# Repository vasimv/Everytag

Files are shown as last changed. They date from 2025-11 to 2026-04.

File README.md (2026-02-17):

# Everytag
The firmware emulates Apple Airtag (up to 40 public keys rotating at default 10 minutes interval) and Google Find My Device (just one non-rotating key at the moment). It works on nRF52/54 chips and uses Zephyr. I've tried to optimize power consumption as much as could (microamperes range). MCU's watchdog is used to be sure it always works until battery dies.

One of biggest advantages of the firmware is ability to reconfigure all of its settings via BLE (python script is included), so you can change keys, transmitting power, broadcasting interval and such without reflashing. To minimize power consumption, the firmware accepts connections to change settings only for 2 seconds every minute and has simple password protection.

As beta test feature, it counts current time (if your board has 32.768kHz crystal) and saves current time to the flash periodically, so clock won't drift too much even if it gets reboot.

Also, it is possible to do OTA firmware update on nRF52/54 chips with at least 512KB flash/RRAM memory through mcumgr protocol. That includes nRF52832 (512KB version), nRF52833, nRF54L15. OTA won't work on nRF52805, nRF52810 but you can still change settings through BLE.

## Credits and useful links
Big thanks to OpenHaystack project for their great work: https://github.com/seemoo-lab/openhaystack

The firmware originated as a fork of macless-haystack project and has some of its code: https://github.com/dchristl/macless-haystack

To query locations you can use FindMy scripts: https://github.com/biemster/FindMy

To create Google FMDN key and query locations, use this: https://github.com/leonboe1/GoogleFindMyTools

## Hardware

The firmware has support (see boards/ subdirectory) and tested on these boards and beacons: NRF52DK (nRF52832), NRF54L15DK (nRF54L15), KKM C2 (nRF52805), KKM K4P (K5) with accelerometer (nRF52833), KKM P1 (nRF52810), KKM P11 (nRF52810), Fanstel NRF52805EVM (nRF52805), Minew HCB22E (nRF52832). For NRF52DK, KKM C2 and KKM K4P you will have to use button to turn it on after first flash. On other boards/beacons it'll start right after flashing. Only one LED will blink on the start (1 short, 2 long).

Button (first one on NRF52DK board) can be used to turn off/on. Long press the button until 1 short + 2 long LED flashes to start it on. Same long press for shutdown, it'll do two short flashes and issue sys_poweroff(), less than one microampere in that state. Power on/off status is stored into flash, so it'll stay same after battery replacement (will blink once after installing new battery and return to sleep if was turned off).

Additionally, i've included my design of beacon that has Qi/WPC wireless charging support (nRF52833, BQ51013B, BQ25121A), see hardware/ subdirectory. The goal was to make small and very thin beacon (50x20x2mm with LIR2016 li-ion battery). You can order these assembled on PCBWay https://www.pcbway.com/project/shareproject/Small_and_thin_50x20x2mm_Bluetooth_beacon_with_Qi_WPC_wireless_charging_f97170e6.html (around 35 USD per board).

## Compilation
Zephyr-based nRF Connect SDK 2.8.0 is required to compile the firmware.

myboards.h file has compilation-time settings (like how often switch to settings mode, etc). 

In the Visual Studio Code - click on nrfconnect plugin button, create build configuration for your board. Use following configuration files:

prj-smpsrv.conf - debug (through J-Link RTT interface) version with mcumgr support (for 512KB or bigger flash chips). You can use JlinkRTTViewer to connect and see debug messages on its console.

prj-smpsrv-lowpower.conf - no debug version for lowest power consumption and memory usage, with mcumgr support

prj.conf - debug version without mcumgr support (no mcuboot) for small memory chips - nRF52805, nRF52810, nRF52811

prj-lowpower.conf - no debug version for these chips

For nRF52DK/nrf52832 and nRF54L15DK - use nrf52832dk.overlay / nrf54l15dk.overlay files as "Extra Devicetree overlays"

## Running
It is recommended to erase all flash memory before first run to reset NVS storage where the firmware stores its settings.

Disconnect power source (remove battery) for 10-20 seconds and reconnect again after flashing through SWD or using RTT debug console, nrf chips often switch to high power consumption (up to few milliamps range) after using Jlink RTT interface and software reset doesn't help. So far, i haven't found way to avoid that.

By default, the firmware will start broadcasting dummy iBeacon packets with 7 seconds interval at very low power (-8dBm) with TX power field set as battery voltage (like 31 is 3.1 volts). This broadcast will stop as soon as you load Apple Airtag and/or Google FMDN key.

The beacon will use default MAC address (from MCU's registers programmed at factory) for iBeacon and settings broadcasts. You can figure out the address via debug console or using an BLE scanning app (nrfconnect from Nordic is quite good and free) on a smartphone.

## Changing settings via BLE
Every minute it will switch into settings mode for 2 seconds (configurable) and settings (including keys) can be changed by conn_beacon.py script (requires python 3) or by using android application that AI did generate for me (see below). Note, bluez isn't really perfect stack to work with BLE and the script may have troubles while connecting to the beacon. To fix that, you may try to disable/enable bluetooth or even reboot your computer.

The script is used for:
1. Changing its settings and/or writing current time to the beacon
2. Reading current time from the beacon
3. Switching the beacon into mcumgr OTA mode for one minute

All of these requires password authentication (default password is "abcdefgh", can be changed via settings mode too)

Note, after loading an Airtag key, MAC address in settings mode will be changed, it is recommended to set a specific MAC address for the settings mode when loading an Airtag key. Otherwise, you will have to figure out current MAC address via nrfconnect app or in a similar way.

Examples:
`python3 conn_beacon.py -i e7:93:3a:cc:f6:61 -c e7:93:3a:cc:f6:61 -a abcdefgh -n h45edc78 -f f1e101731f1e1b312272f812e521293a3f484414 -k ~/airtags/016WX1_keyfile -p 2 -g 1 -t 1 -w 1 -d 2`

This will connect to beacon with E7:93:3A:CC:F6:61 MAC address, change password to "h45edc78" load airtag key from 016WX1_keyfile, load FMDN key "f1e101731f1e1b312272f812e521293a3f484414", set maximum TX power (+4 or +8 dBm), allow broadcasting both Airtag and FMDN, switching every 2 seconds. You can omit some settings you don't want to change, only MAC address (-i) and authorization code (-a) is required.

`python3 conn_beacon.py -i e7:93:3a:cc:f6:61 -a h45edc78 -w 1`

This will connect to the beacon and synchronize its clock to current time.

`python3 conn_beacon.py -i e7:93:3a:cc:f6:61 -a h45edc78 -r 1`

This will connect to the beacon and read current time

To use OTA update feature, see flash_beacon.sh and flash_list.sh. Debug/lowpower versions of the mcumgr stuff may be uncompatible between each other, so you may get troubles with reflashing over bluetooth if flashed wrong version first. Settings are stored in separate region of flash/RRAM and they will be same after OTA, use full chip erase through SWD to get rid of old settings or use conn_beacon.py to program new ones.

## Using android application to change settings
Check subdirectory tagcheck for the android application. I have around zero knowledge about the android application development, so ChatGPT did wrote it for me. Sorry for its general ugliness, i'm not an UI guy. This is AndroidStudio project and you can compile it by yourself or use apk included.

"SCAN BLE" functionality will find all BLE stuff with RSSI is bigger than specififed value. This will help to find MAC address of your beacon (place it very close to the phone's bluetooth antenna, so RSSI will be bigger). You can tap on one of scanned results to fill target's MAC address to send settings instead of typing MAC manually.

On settings screen you can choose which settings to update on the Everytag beacon by activating their respective checkboxes. You have to set target MAC address and password (authorization code) to be able to reconfigure beacon. You will need to upload an airtag keyfile to the phone to change its broadcast key.

"Firmware Update" will upgrade firmware through BLE, you have to upload zephyr.signed.bin to your phone first.

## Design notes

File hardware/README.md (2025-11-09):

## Bluetooth beacon design with Qi/WPC charging

The goal of the project was to make thin and small BLE beacon that uses Li-Ion battery and can be recharged with wireless charging. Note, it may not work with all Qi/WPC chargers because small receiving charging coil, it is highly recommended to adapt charger by replacing its transmitting coil with small 20mm diameter coil. I've used Wurth 760308101104 coil with Adafruit 2162 Qi/WPC charger module.

Final size with LIR2016 battery - 50x20x2mm in thin variant. If height is not limited, then battery can be placed above the board and size will be 30x20mm. A ferrite gasket 20x15mm plate is strongly recommended to be glued on the receiving coil, i've used Wurth 74274119 in that role. 5x1mm round magnet can be placed in the hole on the board and transmitting antenna, so both coils will self-align while charge.

When placed on a Qi/WPC charger - reset pulse will be generated for the MCU, keep that in mind if you want to use with your own firmwares. BQ25121A is used in I2C-only configuration to simplify PCB design, you have to configure charging current, voltages and such during MCU initialization.

BQ25121A and 0402 sized components are quite hard to solder manually, so you may want to order them assembled! Link on PCBWay: https://www.pcbway.com/project/shareproject/Small_and_thin_50x20x2mm_Bluetooth_beacon_with_Qi_WPC_wireless_charging_f97170e6.html

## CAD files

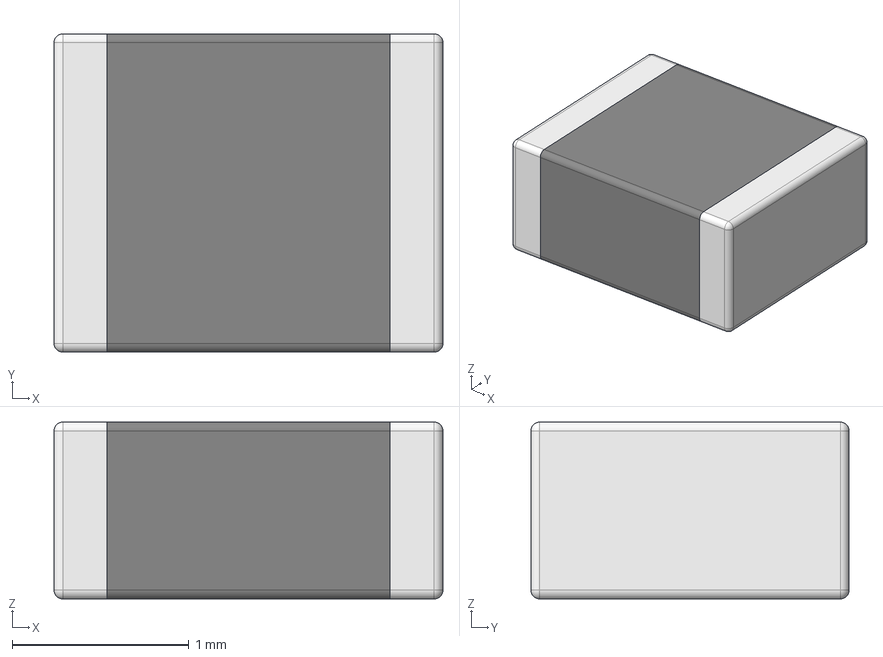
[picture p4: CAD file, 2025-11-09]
hardware/ALTIUM_EMBEDDED_MODELS/INDC2016X10N.step
2.20 x 1.80 x 1.00 mm

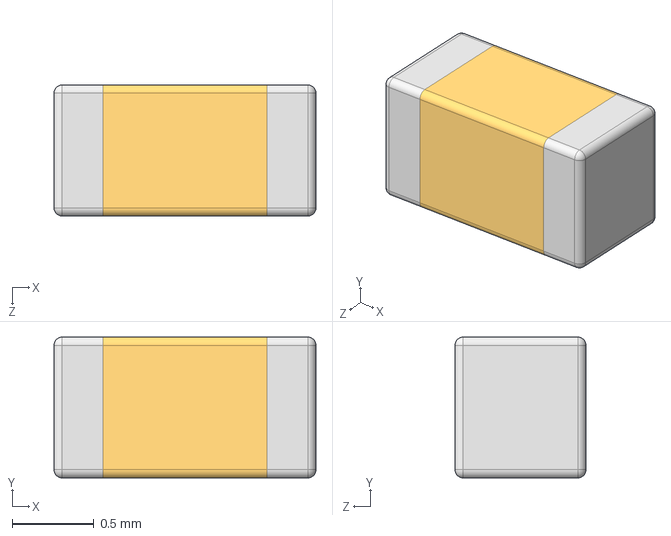
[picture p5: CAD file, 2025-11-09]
hardware/ALTIUM_EMBEDDED_MODELS/User Library-Chip Capacitor 0603.step
1.60 x 0.86 x 0.8 mm

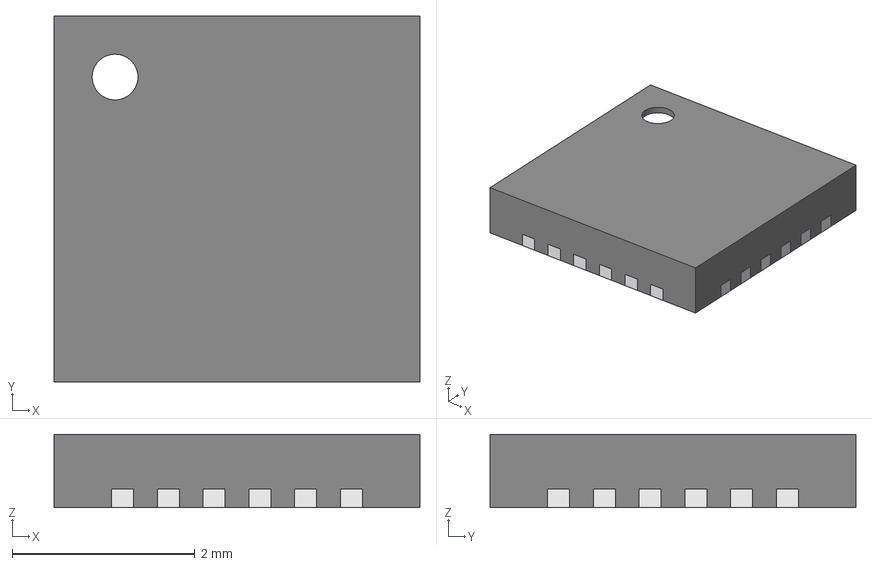
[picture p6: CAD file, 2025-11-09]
hardware/ALTIUM_EMBEDDED_MODELS/QFN50P400X400X80_HS-25N.step
4.00 x 4.00 x 0.801 mm
Thermal_Shape

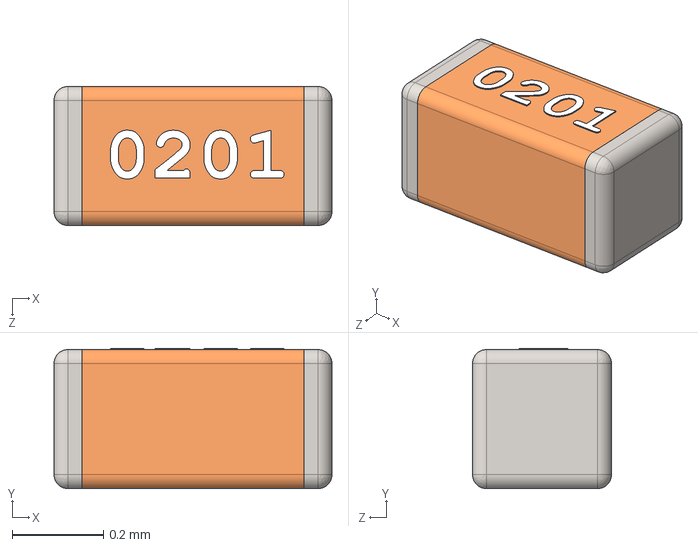
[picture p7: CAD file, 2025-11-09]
hardware/ALTIUM_EMBEDDED_MODELS/User Library-0201(0603M) Cap.step
0.61 x 0.307 x 0.305 mm

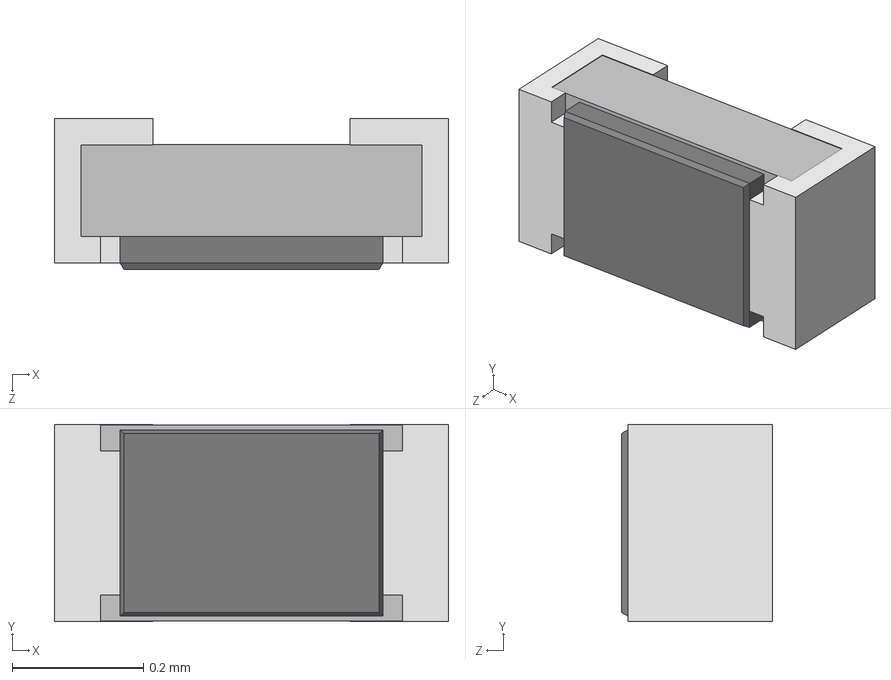
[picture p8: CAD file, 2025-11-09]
hardware/ALTIUM_EMBEDDED_MODELS/User Library-res0201-1.step
0.6 x 0.3 x 0.23 mm

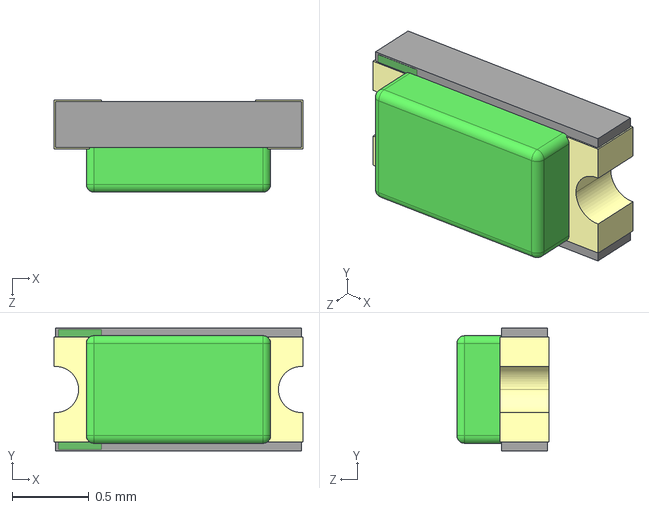
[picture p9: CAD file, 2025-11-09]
hardware/ALTIUM_EMBEDDED_MODELS/User Library-led_0603_green.step
1.62 x 0.8 x 0.6 mm

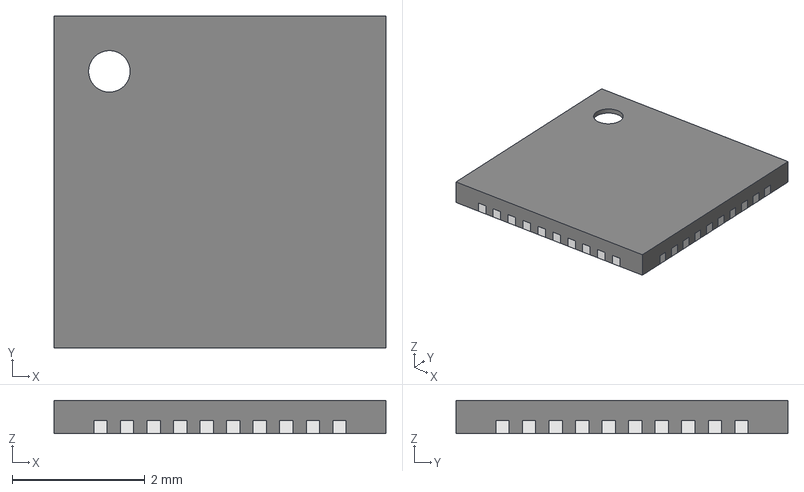
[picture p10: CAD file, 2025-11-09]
hardware/ALTIUM_EMBEDDED_MODELS/QFN40P500X500X50_HS-41N.step
5.00 x 5.00 x 0.501 mm
Thermal_Shape

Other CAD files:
hardware/ALTIUM_EMBEDDED_MODELS/User Library-led_0603_red.step

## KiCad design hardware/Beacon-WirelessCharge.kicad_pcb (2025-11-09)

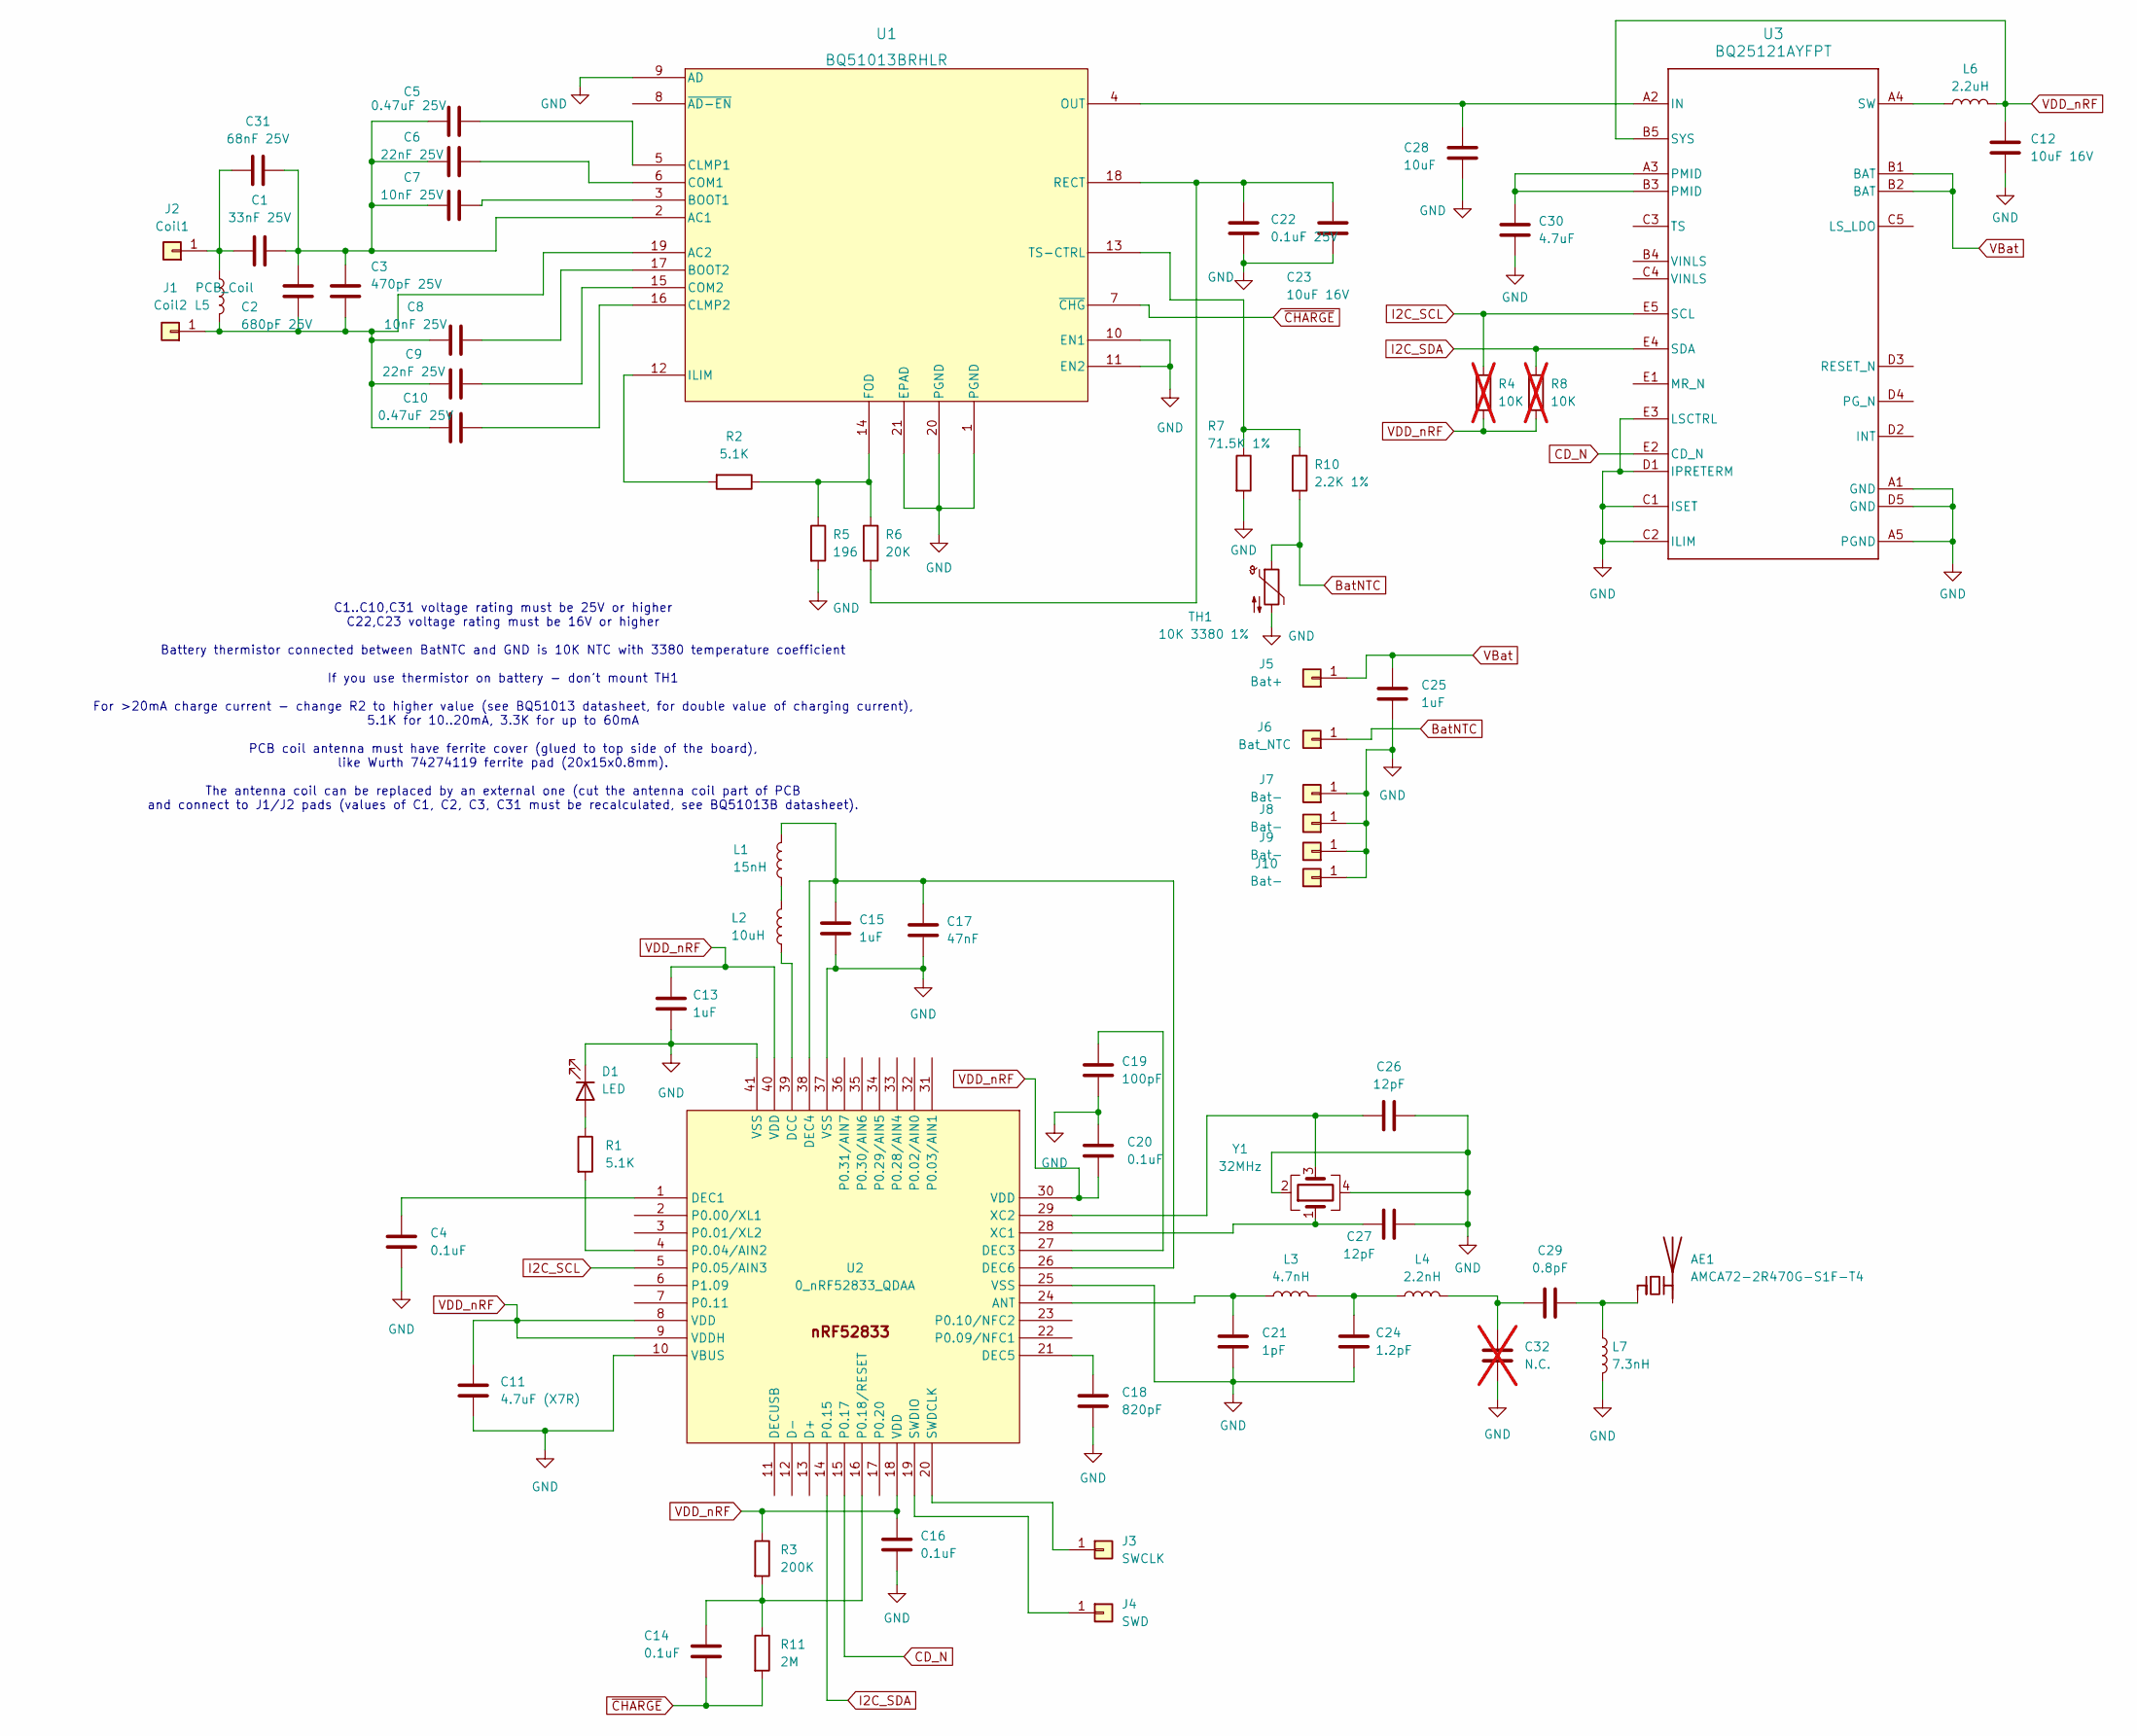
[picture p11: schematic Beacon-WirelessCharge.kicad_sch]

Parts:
AE1: AMCA72-2R470G-S1F-T4; Antenna_2450AT43A100
C1: 33nF 25V; C_0402_1005Metric
C2: 680pF 25V; C_0402_1005Metric
C3: 470pF 25V; C_0402_1005Metric
C4, C14, C16, C20: 0.1uF; C_0402_1005Metric
C5, C10: 0.47uF 25V; C_0402_1005Metric
C6, C9: 22nF 25V; C_0402_1005Metric
C7, C8: 10nF 25V; C_0402_1005Metric
C11: 4.7uF (X7R); C_0603_1608Metric
C12, C23: 10uF 16V; C_0603_1608Metric
C13, C15, C25: 1uF; C_0402_1005Metric
C17: 47nF; C_0402_1005Metric
C18: 820pF; C_0402_1005Metric
C19: 100pF; C_0402_1005Metric
C21: 1pF; C_0402_1005Metric
C22: 0.1uF 25V; C_0402_1005Metric
C24: 1.2pF; C_0402_1005Metric
C26, C27: 12pF; C_0402_1005Metric
C28: 10uF; C_0402_1005Metric
C29: 0.8pF; C_0402_1005Metric
C30: 4.7uF; C_0402_1005Metric
C31: 68nF 25V; C_0402_1005Metric
C32: N.C.; C_0402_1005Metric; not fitted
D1: LED; D_0402_1005Metric
J1: Coil2; Pin-1.5_1.5mm
J2: Coil1; Pin-1.5_1.5mm
J3: SWCLK; Pin-1.5_1.5mm
J4: SWD; Pin-1.5_1.5mm
J5: Bat+; Pin-1.5_1.5mm
J6: Bat_NTC; Pin-1.5_1.5mm
J7, J8, J9, J10: Bat-; Pin-1.5_1.5mm
L1: 15nH; L_0402_1005Metric
L2: 10uH; L_0603_1608Metric
L3: 4.7nH; L_0402_1005Metric
L4: 2.2nH; L_0402_1005Metric
L5: PCB_Coil; antenna 19x13mm
L6: 2.2uH; L_0603_1608Metric
L7: 7.3nH; L_0402_1005Metric
R1, R2: 5.1K; R_0402_1005Metric
R3: 200K; R_0402_1005Metric
R4, R8: 10K; R_0402_1005Metric; not fitted
R5: 196; R_0402_1005Metric
R6: 20K; R_0402_1005Metric
R7: 71.5K 1%; R_0402_1005Metric
R10: 2.2K 1%; R_0402_1005Metric
R11: 2M; R_0402_1005Metric
TH1: 10K 3380 1%; R_0402_1005Metric
U1: BQ51013BRHLR; RHL20_2P05X3P05
U2: 0_nRF52833_QDAA; _Applications_test_rsk_lib_RSK-ONLY_Nordic Active DB.DbLib_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; PART NUMBER nRF52833-QDAA
U3: BQ25121AYFPT; BGA25C40P5X5_247X253X50
Y1: 32MHz; Crystal_SMD_2016-4Pin_2.0x1.6mm

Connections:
BatNTC: J6.1, R10.2, TH1.1
CD_N: U2.15 (P0.17), U3.E2 (CD_N)
GND: C4.2, C11.2, C12.2, C13.2, C15.2, C16.2, C17.2, C18.2, C19.2, C20.1, C21.2, C22.2, C23.2, C24.2, C25.2, C26.2, C27.2, C28.2, C30.2, C32.2, D1.1 (K), J7.1, J8.1, J9.1, J10.1, L7.2, R5.2, R7.2, TH1.2, U1.1 (PGND), U1.9 (AD), U1.10 (EN1), U1.11 (EN2), U1.20 (PGND), U1.21 (EPAD), U2.10 (VBUS), U2.25 (VSS), U2.37 (VSS), U2.41 (VSS), U3.A1 (GND), U3.A5 (PGND), U3.C1 (ISET), U3.C2 (ILIM), U3.D1 (IPRETERM), U3.D5 (GND), U3.E3 (LSCTRL), Y1.2, Y1.4
I2C_SCL: R4.1, U2.5 (P0.05/AIN3), U3.E5 (SCL)
I2C_SDA: R8.1, U2.14 (P0.15), U3.E4 (SDA)
unnamed: AE1.1 (FEED), C29.2, L7.1
unnamed: C24.1, L3.2, L4.1
unnamed: C29.1, C32.1, L4.2
unnamed: C30.1, U3.A3 (PMID), U3.B3 (PMID)
unnamed: D1.2 (A), R1.1
unnamed: C2.2, C3.2, C8.1, C9.1, C10.1, J1.1, L5.2, U1.19 (AC2)
unnamed: C1.1, C31.1, J2.1, L5.1
unnamed: J3.1, U2.20 (SWDCLK)
unnamed: J4.1, U2.19 (SWDIO)
unnamed: L1.1, L2.2
unnamed: C1.2, C2.1, C3.1, C5.1, C6.1, C7.1, C31.2, U1.2 (AC1)
unnamed: C7.2, U1.3 (BOOT1)
unnamed: C8.2, U1.17 (BOOT2)
unnamed: C5.2, U1.5 (CLMP1)
unnamed: C10.2, U1.16 (CLMP2)
unnamed: C6.2, U1.6 (COM1)
unnamed: C9.2, U1.15 (COM2)
unnamed: R2.1, R5.1, R6.1, U1.14 (FOD)
unnamed: R2.2, U1.12 (ILIM)
unnamed: C28.1, U1.4 (OUT), U3.A2 (IN)
unnamed: C22.1, C23.1, R6.2, U1.18 (RECT)
unnamed: R7.1, R10.1, U1.13 (TS-CTRL)
unnamed: C21.1, L3.1, U2.24 (ANT)
unnamed: L2.1, U2.39 (DCC)
unnamed: C4.1, U2.1 (DEC1)
unnamed: C19.1, U2.27 (DEC3)
unnamed: C15.1, C17.1, L1.2, U2.26 (DEC6), U2.38 (DEC4)
unnamed: C18.1, U2.21 (DEC5)
unnamed: R1.2, U2.4 (P0.04/AIN2)
unnamed: C14.1, R3.2, R11.1, U2.16 (P0.18/RESET)
unnamed: C27.1, U2.28 (XC1), Y1.1
unnamed: C26.1, U2.29 (XC2), Y1.3
unnamed: L6.1, U3.A4 (SW)
VBat: C25.1, J5.1, U3.B1 (BAT), U3.B2 (BAT)
VDD_nRF: C11.1, C12.1, C13.1, C16.1, C20.2, L6.2, R3.1, R4.2, R8.2, U2.8 (VDD), U2.9 (VDDH), U2.18 (VDD), U2.30 (VDD), U2.40 (VDD), U3.B5 (SYS)
~CHARGE: C14.2, R11.2, U1.7 (~CHG)

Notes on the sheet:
C1..C10,C31 voltage rating must be 25V or higher C22,C23 voltage rating must be 16V or higher Battery thermistor connected between BatNTC and GND is 10K NTC with 3380 temperature coefficient If you use thermistor on battery - don't mount TH1 For >20mA charge current - change R2 to higher value (see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

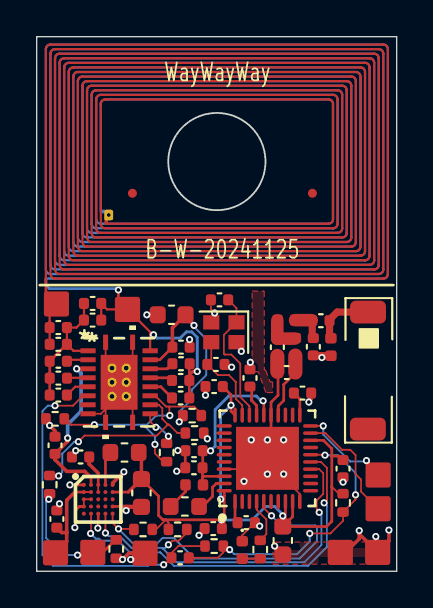
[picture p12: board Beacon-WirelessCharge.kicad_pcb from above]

Board: 2 copper layers, 20.0 x 29.7 mm, 68 parts (1 on the bottom side), 41 nets.

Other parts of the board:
Fiducial_0.5_1_A, Fiducial_0.5_1_B: Fiducial_0.5mm_Mask1mm

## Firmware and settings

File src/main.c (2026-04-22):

/*
 * Copyright (c) 2018 Henrik Brix Andersen <henrik@brixandersen.dk>
 *
 * SPDX-License-Identifier: Apache-2.0
 */

#include <stdlib.h>
#include <zephyr/types.h>
#include <stddef.h>
#include <zephyr/sys/printk.h>
#include <zephyr/sys/util.h>
#include <zephyr/sys/byteorder.h>

#include <zephyr/bluetooth/bluetooth.h>
#include <zephyr/bluetooth/hci.h>
#include <zephyr/bluetooth/hci_vs.h>
#include <zephyr/sys/poweroff.h>

#include <zephyr/kernel.h>
#include <zephyr/device.h>
#include <zephyr/drivers/gpio.h>
#include <zephyr/bluetooth/controller.h>
#include <zephyr/pm/pm.h>
#include <zephyr/pm/device.h>
#include <zephyr/drivers/adc.h>
#include <zephyr/drivers/i2c.h>
#include <zephyr/drivers/timer/system_timer.h>
#include <zephyr/sys/reboot.h>
#include <zephyr/irq.h>
#include <zephyr/drivers/hwinfo.h>

#include "myboards.h"
#include "settings.h"
#include "watchdog.h"
#ifdef USE_BQ25121A
#include "bq2512x.h"
#endif
#ifdef USE_LIS2DW12
#include "lis2dw12.h"
#endif

#define BROADCAST_INTERVAL_MIN 1500 // 938ms
#define BROADCAST_INTERVAL_MAX 1590 // 994ms

#if !DT_NODE_EXISTS(DT_PATH(zephyr_user)) || \
	!DT_NODE_HAS_PROP(DT_PATH(zephyr_user), io_channels)
#warning "No suitable devicetree node, battery check disabled"
#define NO_BATTERY_CHECK
#endif

#ifndef NO_BATTERY_CHECK
#define DT_SPEC_AND_COMMA(node_id, prop, idx) \
	ADC_DT_SPEC_GET_BY_IDX(node_id, idx),

/* Data of ADC io-channels specified in devicetree. */
static const struct adc_dt_spec adc_channels[] = {
	DT_FOREACH_PROP_ELEM(DT_PATH(zephyr_user), io_channels,
			     DT_SPEC_AND_COMMA)
};
#endif

#if CONFIG_GPIO
#define LED_NODE DT_NODELABEL(led0)
static const struct gpio_dt_spec led_spec = GPIO_DT_SPEC_GET(LED_NODE, gpios);
#define GPIO_ID DT_NODELABEL(gpio0)
#ifdef HAS_LED1_SWITCH
#define LED1_NODE DT_NODELABEL(led1)
static const struct gpio_dt_spec gate_spec = GPIO_DT_SPEC_GET(LED1_NODE, gpios);
#endif
#endif

#ifdef HAS_I2C_KXTJ3
#define I2C0_NODE DT_NODELABEL(kxtj3)
static const struct i2c_dt_spec dev_i2c = I2C_DT_SPEC_GET(I2C0_NODE);
const struct device *const i2c_dev = DEVICE_DT_GET(DT_NODELABEL(i2c0));
#endif

#ifdef USE_BUTTON
static const struct gpio_dt_spec sw0 = GPIO_DT_SPEC_GET(DT_ALIAS(sw0), gpios);
#endif

void blink_led(int num, int fast) {
	int err;

#if CONFIG_GPIO
#if CONFIG_PM_DEVICE_RUNTIME
  	err = pm_device_action_run(DEVICE_DT_GET(DT_NODELABEL(gpio0)), PM_DEVICE_ACTION_RESUME);
	if (err)
		printk("Warning: Can't turn on gpio0 (err %d)\n", err);
#endif
	gpio_pin_configure_dt(&led_spec, GPIO_OUTPUT_INACTIVE);
	k_sleep(fast ? K_MSEC(250) : K_MSEC(1000));
	for (int i = 0; i < (2*num); i++) {
		gpio_pin_toggle_dt(&led_spec);
		k_sleep(fast ? K_MSEC(100) : K_MSEC(200));
	}
#if CONFIG_PM_DEVICE_RUNTIME
	gpio_pin_configure_dt(&led_spec, GPIO_DISCONNECTED);
	err = pm_device_action_run(DEVICE_DT_GET(DT_NODELABEL(gpio0)), PM_DEVICE_ACTION_SUSPEND);
	if (err)
		printk("Warning: Can't turn off gpio0 (err %d)\n", err);
#endif
#endif
}

int lastBatteryVoltage = 0;

#ifdef USE_BQ25121A
int check_charging() {
	return bq2512x_is_charging();
}

int battery_voltage(void) {
	return bq2512x_lastVoltage;
}
#else
int check_charging() {
	// There is no way to check if we're charging on boards without BQ25121A
	return 0;
}

int battery_voltage(void) {
#ifndef NO_BATTERY_CHECK
	int err;
	int32_t val_mv;
	int16_t buf = 0;
	uint8_t level = 0;
	int64_t sum_mv = 0;
	int i;

#if CONFIG_PM_DEVICE_RUNTIME
	err = pm_device_action_run(DEVICE_DT_GET(DT_NODELABEL(adc)), PM_DEVICE_ACTION_RESUME);
	if (err)
		printk("Warning: Can't turn on adc0 (err %d)\n", err);
#endif
	struct adc_sequence sequence = {
		.buffer = &buf,
		/* buffer size in bytes, not number of samples */
		.buffer_size = sizeof(buf),
	};

	if (!device_is_ready(adc_channels[0].dev)) {
		printk("ADC controller device not ready\n");
		return level;
	}
	err = adc_channel_setup_dt(&adc_channels[0]);
	if (err < 0) {
		printk("Could not setup channel #%d (%d)\n", 0, err);
		return level;
	}
	(void)adc_sequence_init_dt(&adc_channels[0], &sequence);

	// read adc 8 times to average
	for (i = 0; i < BATTERY_ADC_SAMPLES; i++) {
		err = adc_read(adc_channels[0].dev, &sequence);
		if (err < 0) {
			printk("Could not read (%d)\n", err);
		return level; 
		}

		val_mv = buf;
		err = adc_raw_to_millivolts_dt(&adc_channels[0], &val_mv);
		if (err < 0) {
			printk(" (value in mV not available)\n");
			return level; 
		}
		k_sleep(K_MSEC(5));
		sum_mv += val_mv;
	}
	val_mv = BATTERY_MULTIPLIER * (sum_mv / BATTERY_ADC_SAMPLES);

	printk("voltage level: %d\n", val_mv);
#if CONFIG_PM_DEVICE_RUNTIME
	err = pm_device_action_run(DEVICE_DT_GET(DT_NODELABEL(adc)), PM_DEVICE_ACTION_SUSPEND);
	if (err)
		printk("Warning: Can't turn off adc0 (err %d)\n", err);
#endif

  lastBatteryVoltage = val_mv;
	return val_mv;
#else
	return 0;
#endif
}
#endif


// airtag advertising data
struct bt_data adv_airtag[] = {
  BT_DATA_BYTES(BT_DATA_MANUFACTURER_DATA,
          0x4c, 0x00, 0x02, 0x15, 0x18, 0xee, 0x15, 0x16,
          0x01, 0x6b, 0x4b, 0xec, 0xad, 0x96, 
          0xbc, 0xb9, 0x6d, 0x16, 0x6e, 0x97, 
          0x00, 0x00, 0x00, 0x00, 0x00, 0x00, 0x00, 0x00, 0x00
  ),
};

// fmdn advertising data
struct bt_data adv_fmdn[] = {
  BT_DATA_BYTES(BT_DATA_FLAGS, BT_LE_AD_NO_BREDR | BT_LE_AD_GENERAL),
  BT_DATA_BYTES(
    0x16, 0xAA, 0xFE, 0x41,
    // public key
    0x00, 0x00, 0x00, 0x00, 0x00, 0x00, 0x00, 0x00, 0x00, 0x00, 0x00, 0x00, 0x00, 0x00, 0x00, 0x00, 0x00, 0x00, 0x00, 0x00,
    // status
    0xc0
  ),
};

struct bt_data adv_ibeacon[] = {
  BT_DATA_BYTES(BT_DATA_FLAGS, BT_LE_AD_NO_BREDR),
  BT_DATA_BYTES(    0xff,       /* Manufacturer Specific Data (type 0xff) */
              0x4c, 0x00, /* Apple */
              0x02, 0x15, /* iBeacon */
              0x18, 0xee, 0x15, 0x16, /* UUID[15..12] */
              0x01, 0x6b, /* UUID[11..10] */
              0x4b, 0xec, /* UUID[9..8] */
              0xad, 0x96, /* UUID[7..6] */
              0xbc, 0xb9, 0x6d, 0x16, 0x6e, 0x97, /* UUID[5..0] */
              0x1, 0x1, /* Major */
              0x1, 0x1, /* Minor */ /* Hint (0x00) */
        0x0,
)
};

// MAC address (calculated from airtag key unless only FMDN broadcasting)
uint8_t bleAddr[6] = {0xFF, 0xBB, 0xCC, 0xDD, 0xEE, 0xFF};

static uint8_t offline_finding_adv_template[] = {
	0x1e,		/* Length (30) */
	0xff,		/* Manufacturer Specific Data (type 0xff) */
	0x4c, 0x00, /* Company ID (Apple) */
	0x12, 0x19, /* Offline Finding type and length */
	0xAA,		/* Status */
	0x00, 0x00, 0x00, 0x00, 0x00, 0x00, 0x00, 0x00,
	0x00, 0x00, 0x00, 0x00, 0x00, 0x00, 0x00, 0x00,
	0x00, 0x00, 0x00, 0x00, 0x00, 0x00,
	0x00, /* First two bits */
	0x00, /* Hint (0x00) */
};

uint8_t airtag_data_store[sizeof(offline_finding_adv_template)];
uint8_t fmdn_data_store[25];

#ifdef USE_ACCELEROMETER

// Make 7-bits array from accelerometer movements data
int calc_accel_byte() {
  int res = 0;
  
  // bit 0 - movements in 0..10 minutes
  // bit 1 - in 10..30 minutes
  // bit 2 - in 30..60 minutes
  // bit 3 - in 1..3 hours
  // bit 4 - in 3..6 hours
  // bit 5 - in 6..12 hours
  // bit 6 - in 12..24 hours
  if (accel_movement(0, 10))
    res |= 0x01;
  if (accel_movement(10, 30))
    res |= 0x02;
  if (accel_movement(30, 60))
    res |= 0x04;
  if (accel_movement(60, 180))
    res |= 0x08;
  if (accel_movement(180, 360))
    res |= 0x10;
  if (accel_movement(360, 720))
    res |= 0x20;
  if (accel_movement(720, 1440))
    res |= 0x40;
    
  return res;
}
#endif

// Status byte behaviour
// first two bytes - specific byte to broadcast as status for Airtag and FMDN
// 0x10000 - broadcast first byte as status in airtag
// 0x100000 - broadcast second byte as status in FMDN
// 0x20000 - broadcast incrementing (every changeInterval) byte as status in airtag
// 0x200000 - broadcast incrementing byte as status in FMDN
// 0x30000 - broadcast battery voltage as status in airtag (32 - 3.2V)
// 0x300000 - broadcast battery voltage as status in FMDN
// 0x40000 - broadcast battery level (0..3) in airtag with first byte, binary OR
// 0x400000 - broadcast battery level (1..3) in FMDN with second byte, binary OR
// 0x50000 - every minute switch between broadcasting battery voltage, accelerometer and temperature in airtag
// 0x500000 - every minute switch between broadcasting battery voltage, accelerometer and temperature in airtag

// What we're currently sending in status byte (with 0x50000 and 0x500000)
// 0 - battery voltage, 1 - accelerometer, 2 - temperature
static int what_in_status = 2;

static int keys_changes = 0;

// Update status byte in Airtag/FMDN advertisement broadcasts (see settings.h)
void update_status_byte() {
  uint8_t statusAirtag, statusFmdn;
  int bAirtag, bFmdn;

  what_in_status++;
  if (what_in_status > 2)
    what_in_status = 0;

  statusAirtag = statusFlags & 0xff;
  statusFmdn = (statusFlags & 0xff00) >> 8;
  bAirtag = (statusFlags & 0xf0000) >> 16;
  bFmdn = (statusFlags & 0xf00000) >> 20;
  printk("update_status_byte: battery: %d Airtag %d:%02X, %d:%02X\n", lastBatteryVoltage, bAirtag, statusAirtag, bFmdn, statusFmdn);
  // Setting status for airtag
  switch (bAirtag) {
    case 1:
      // Broadcast first byte from statusFlags as is
      break;
    case 2:
      // Broadcast incrementing byte as status byte
      statusAirtag = keys_changes & 0xff;
      break;
    case 3:
    case 5:
      // Broadcast battery voltage in status byte
      statusAirtag = lastBatteryVoltage / 100;
      if ((bAirtag == 3) || (what_in_status == 0))
        break;
      #ifdef USE_ACCELEROMETER
      if (what_in_status == 1) {
        statusAirtag = 0x80 | calc_accel_byte();
        printk("update_status_byte: switching to acceldata %02x\n", (int) statusAirtag);
      }
      if (what_in_status == 2) {
        // Send temperature in -10..53C range as positive 6-bit integer (-10 is 0, 53 is 63)
        int tmpTemp = (accelTemperature + 5) / 10 + 10;
        if (tmpTemp < 0)
          tmpTemp = 0;
        if (tmpTemp > 63)
          tmpTemp = 63;
        statusAirtag = 0x40 | tmpTemp;
        printk("update_status_byte: switching to temperature %02x\n", (int) statusAirtag);
      }
      #endif
      break;
    case 4:
      // Broadcast battery status
      int battery = 3;
      if (lastBatteryVoltage > BATTERY_LEVEL_FULL)
        battery = 0;
      else {
        if (lastBatteryVoltage > BATTERY_LEVEL_NORMAL)
          battery = 1;
        else {
          if (lastBatteryVoltage > BATTERY_LEVEL_LOW)
            battery = 2;
          else
            battery = 3;
        }
      }
      statusAirtag |= (battery << 6);
      break;
    default:
      break;
  }
  airtag_data_store[6] = statusAirtag;

  // Setting status for FMDN
  switch (bFmdn) {
    case 1:
      // Broadcast first byte from statusFlags as is
      break;
    case 2:
      // Broadcast incrementing byte as status byte
      statusFmdn = keys_changes & 0xff;
      break;
    case 3:
    case 5:
      // Broadcast battery voltage in status byte
      statusFmdn = lastBatteryVoltage / 100;
      #ifdef USE_ACCELEROMETER
      if (what_in_status == 1)
        statusFmdn = 0x80 | calc_accel_byte();
      if (what_in_status == 2) {
        // Send temperature in -10..53C range as positive 6-bit integer (-10 is 0, 53 is 63)
        int tmpTemp = (accelTemperature + 5) / 10 + 10;
        if (tmpTemp < 0)
          tmpTemp = 0;
        if (tmpTemp > 63)
          tmpTemp = 63;
        statusFmdn = 0x40 | tmpTemp;
      }
      #endif
      break;
    case 4:
      // Broadcast battery status
      int battery = 0;
      if (lastBatteryVoltage > BATTERY_LEVEL_NORMAL)
        battery = 1;
      else {
        if (lastBatteryVoltage > BATTERY_LEVEL_LOW)
          battery = 2;
        else {
          if (lastBatteryVoltage > 0)
            battery = 3;
          else
            battery = 0;
        }
      }
      statusFmdn |= (battery << 5);
      break;
    default:
      break;
  }
  fmdn_data_store[23] = statusFmdn;
}

/*
 * set_addr_from_key will set the bluetooth address from the first 6 bytes of the key used to be advertised
 */
void set_addr_from_key(const char *key)
{
	/* copy first 6 bytes */
	bleAddr[5] = key[0] | 0b11000000;
	bleAddr[4] = key[1];
	bleAddr[3] = key[2];
	bleAddr[2] = key[3];
	bleAddr[1] = key[4];
	bleAddr[0] = key[5];
}

/*
 * fill_adv_template_from_key will set the advertising data based on the remaining bytes from the advertised key
 */
void fill_adv_template_from_key(const char *key)
{
	memcpy(&offline_finding_adv_template[7], &key[6], 22);
	/* append two bits of public key */
	offline_finding_adv_template[29] = key[0] >> 6;
}

/*
 * setAdvertisementKey will setup the key to be advertised
 *
 * @param[in] key public key to be advertised
 * @param[out] bleAddr bluetooth address to setup
 * @param[out] data raw data to advertise
 *
 * @returns raw data size
 */
uint8_t setAdvertisementKey(const char *key, uint8_t **data)
{
  uint8_t status_save;

	set_addr_from_key(key);
	fill_adv_template_from_key(key);

	*data = airtag_data_store;
  status_save = airtag_data_store[6];
	memcpy(*data, offline_finding_adv_template, sizeof(offline_finding_adv_template));
  airtag_data_store[6] = status_save;
	return sizeof(offline_finding_adv_template);
}
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
int main(void)
{
	int err;
	int badPower = 0;
  int button_at_start = 0;
	
	my_wdt_init();

	printk("Beacon starting\n");

	blink_led(1, 1);
#ifdef USE_BUTTON
  /* Configure button pin */
	err = gpio_pin_configure_dt(&sw0, GPIO_INPUT);
	if (err < 0) {
		printk("Could not configure sw0 GPIO (%d)\n", err);
		return 0;
	}
  if (gpio_pin_get(sw0.port, sw0.pin) > 0)
    button_at_start = 1;
#endif

#ifdef HAS_LED1_SWITCH
	// Turn off mosfet
	gpio_pin_configure_dt(&gate_spec, GPIO_OUTPUT_ACTIVE);
#endif

	my_wdt_feed();
	init_settings();

#ifdef USE_BUTTON
  // Check if wake up button is pressed or go to power down state
  if (button_at_start) {
    printk("Button is pressed, turning on!\n");
    turnedOn = 1;
    update_turnedOn();
  } else {
    // If we weren't turned on by button then go to sleep again
    if (!turnedOn) {
      printk("We are not turned on, sleep again!\n");
      k_sleep(K_MSEC(500));
      my_poweroff();
      return 0;
    }
  }
#endif

#ifdef USE_BQ25121A
	// Repeat twice at start to be sure the bq25121a received settings
	bq2512x_reinit(1, SYS_VOLTAGE, CHARGE_CURRENT, PRECHARGE_CURRENT);
	k_sleep(K_MSEC(10));
	bq2512x_reinit(1, SYS_VOLTAGE, CHARGE_CURRENT, PRECHARGE_CURRENT);
#endif
#ifdef USE_ACCELEROMETER
  for (int i = 0; i < 3; i++)
    if (!accel_init())
      break;
  // Turn off accelerometer if threshold is zero
  if (accelThreshold <= 0)
    (void) accel_powerdown();
#endif

  // Set FMDN advertising data
  switch_fmdn_key(0);

	printk("keys in memory = %d\n", numKeys);
  currentKey = 0;
	switch_airtag_key(currentKey);
  if (flagAirtag || flagFmdn)
    set_MAC_addr(bleAddr);
  else
    if (settingsMAC[0] != 0 && settingsMAC[5] != 0)
      set_MAC_addr(settingsMAC);

  broadcastingAnything = 0;
  broadcastingAirtag = 0;
  broadcastingFmdn = 0;
  broadcastingSettings = 0;

	update_battery();
  update_status_byte();

	/* Initialize the Bluetooth Subsystem */
	err = bt_enable(NULL);
	printk("Bluetooth initialized (err=%d)\n", err);
	
	set_power(txPower);
	my_wdt_feed();
	blink_led(2, 0);

  // Broadcast ibeacon every 7..8 seconds if no airtag or fmdn
  if (!flagAirtag && !flagFmdn)
    broadcast_ibeacon();

  #ifdef USE_BUTTON
  // Wait for button release before getting into main loop
  while (gpio_pin_get(sw0.port, sw0.pin) > 0) {
    k_sleep(K_MSEC(1000));
    my_wdt_feed();
  }
  #endif

	while (1) {
    // In settings mode we do only 2 seconds delay
    if (broadcastingSettings)
      k_sleep(K_MSEC(1000));
    else
      k_sleep(K_MSEC(1000 * multPeriod));
		my_wdt_feed();

		if (chargeLockCounter > 0) 
			chargeLockCounter = chargeLockCounter - multPeriod;

    // Check if we're in settings mode
    if (broadcastingSettings) {
      // Check if settings mode ended
      if (k_uptime_seconds() >= tEndSettings) {
        // Check if someone did connect, wait 2 seconds for auth
        if (connectedGatt || authorizedGatt) {
          k_sleep(K_MSEC(2000));
          my_wdt_feed();
        }
        if (authorizedGatt) {
          k_sleep(K_MSEC(4000));
          my_wdt_feed();
        }
        // Check if we have to wait for firmware upload
        if (pauseUpload) {
          printk("Pause for 60 seconds for firmware upload\n");
          for (int i = 0; i < 15; i++) {
            k_sleep(K_MSEC(4000));
            store_time();
            my_wdt_feed();
          }
          reset_MCU();
          break;
        }

        stop_settings_adv();
        broadcastingSettings = 0;
        broadcastingAnything = 0;
        broadcastingFmdn = 0;
        broadcastingAirtag = 0;
        // Set MAC address back
        bt_disable();
        if (flagAirtag || flagFmdn)
          set_MAC_addr(bleAddr);
        bt_enable(NULL);
        set_power(txPower);
        // Do we have to reset?
        if (needsReset) {
          reset_MCU();
          break;
        }
        // Broadcast ibeacon every 7..8 seconds if no airtag or fmdn
        if (!flagAirtag && !flagFmdn)
          broadcast_ibeacon();
      }

    } else {
      // Update time in NVS storage
      if (k_uptime_seconds() >= (tLastTimeSave + INTERVAL_TIMESAVE)) { 
        tLastTimeSave = k_uptime_seconds();
        store_time();
      }
      // Update battery and store time every minute
      if (k_uptime_seconds() >= (tLastBatteryCheck + INTERVAL_BATTERYCHECK)) {
        tLastBatteryCheck = k_uptime_seconds();
        update_battery();      
        // Update status byte in airtag and fmdn
        update_status_byte();
        if (flagAirtag)
          switch_airtag_key(currentKey);
        if (flagAirtag || flagFmdn)
          broadcast();

				#ifdef BATTERY_UVLO_SHUTDOWN
				// On Li-Ion battery we have to monitor battery voltage and switch to power-save mode when it is too low
				if (battery_voltage() < BATTERY_LOW_VOLTAGE) {
					// Skip UVLO shutdown for one hour if charging is detected
					if (check_charging())
						chargeLockCounter = 3600;

          // Shutdown if we are not charging and battery voltage is too low for 5 minutes at least
					if (chargeLockCounter <= 0) {
						badPower++;
						if (badPower > 5) {
							printk("Battery voltage is too low! Shutting down!\n");
							bt_le_adv_stop();
							#ifdef USE_BQ25121A
							// Fully turn off the system through shipping mode
							bq2512x_shipmode();
							#endif
							my_poweroff();
              return 0;
							// Never should reach here but who knows... Turning off broadcasts, do nothing.
							while (battery_voltage() < BATTERY_LOW_VOLTAGE) {
								update_battery();
								k_sleep(K_MSEC(4000));
								my_wdt_feed();
							}
              reset_MCU();
              break;
						}
					} else {
						printk("Charging in progress was detected, skipping UVLO shutdown\n");
						badPower = 0;
					}
				} else
					badPower = 0;
				#endif
      }

      // Will shutdown after few minutes if no keys loaded and not in charging mode
      #ifdef SHUTDOWN_NOKEYS
      if (!flagAirtag && !flagFmdn && !check_charging() && (k_uptime_seconds() > SHUTDOWN_NOKEYS)) {
        printk("No keys loaded, shutting down!\n");
        blink_led(2, 1);
        #ifdef USE_BQ25121A
        bq2512x_shipmode();
        #endif
        my_poweroff();
        // Never should reach this but who knows...
        k_sleep(K_MSEC(4000));
        reset_MCU();
      }
      #endif

      
      // Switch to settings mode every minute for few seconds
      if (k_uptime_seconds() >= (tLastSettingsMode + INTERVAL_SETTINGS)) {
        tLastSettingsMode = k_uptime_seconds();
        tEndSettings = k_uptime_seconds() + SETTINGS_WAIT;
        bt_le_adv_stop();
        bt_disable();
        // We use other MAC and low power in settings mode
        if (settingsMAC[0] != 0 && settingsMAC[5] != 0)
          set_MAC_addr(settingsMAC);
        bt_enable(NULL);
        set_power(0);
        start_settings_adv();
        broadcastingSettings = 1;
        broadcastingAnything = 1;
        broadcastingFmdn = 0;
        broadcastingAirtag = 0;
        continue;
      }

      // Switch to maximum power every 68 seconds
      if ((txPower != 2) && (flagFmdn && flagAirtag) && (k_uptime_seconds() >= (tLastMaxPower + INTERVAL_MAXPOWER))) {
        tLastMaxPower = k_uptime_seconds();
        tEndMaxPower = k_uptime_seconds() + 2 * multPeriod;
        set_power(2);
      }

      // Return to normal power after two cycles
      if ((tEndMaxPower > 0) && (k_uptime_seconds() >= tEndMaxPower)) {
        tEndMaxPower = 0;
        set_power(txPower);
      }

      // Do we have to switch airtag keys?
      if (flagAirtag && (k_uptime_seconds() >= (tLastAirtagSwitch + changeInterval))) {
        tLastAirtagSwitch = k_uptime_seconds();
  			if (numKeys > 1) {
  				currentKey++;
          if (currentKey >= numKeys)
            currentKey = 0;
        }	else {
  				currentKey = 0;
        }
        keys_changes++;
        bt_le_adv_stop();
  			bt_disable();
        broadcastingAnything = 0;
  			printk("Switching to key %d\n", currentKey);
  			switch_airtag_key(currentKey);
        set_MAC_addr(bleAddr);
  			bt_enable(NULL);
  			set_power(txPower);
  			broadcast();
      }

      #ifdef USE_BUTTON
      // Check if button is pressed and held, then turn off
      if (gpio_pin_get(sw0.port, sw0.pin) > 0) {
        k_sleep(K_MSEC(1000));
        if (gpio_pin_get(sw0.port, sw0.pin) > 0) {
          my_wdt_feed();
          blink_led(2, 1);
          // Wait for button to release
          while (gpio_pin_get(sw0.port, sw0.pin) > 0) {
            k_sleep(K_MSEC(500));
            my_wdt_feed();
          }
          printk("Button was held and released, turning off!\n");
          turnedOn = 0;
          update_turnedOn();
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

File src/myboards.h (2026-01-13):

// Defines for different boards
#ifndef _MYBOARDS_H
#define _MYBOARDS_H

// Settings mode interval (seconds)
#define INTERVAL_SETTINGS 60

// How long we wait for connection in settings mode (seconds)
#define SETTINGS_WAIT 2

// Settings advertisement interval (in milliseconds)
#define SETTINGS_ADV_INTERVAL 400

// How often we save current time in NVS (seconds)
#define INTERVAL_TIMESAVE 3600

// How often we check battery (seconds)
#define INTERVAL_BATTERYCHECK 60

// How often we broadcast with full power (seconds)
#define INTERVAL_MAXPOWER 68

// How many samples to measure battery voltage (including oversampling from .dts)
#define BATTERY_ADC_SAMPLES 3

#if defined(CONFIG_BOARD_WB_20241007)
// Boards with directly connected li-ion battery needs shutdown when voltage is too low
#define BATTERY_MULTIPLIER 5.0
#define BATTERY_UVLO_SHUTDOWN
#define BATTERY_LIION
#else
#define BATTERY_MULTIPLIER 1.0
#endif

#ifdef CONFIG_BOARD_KKM_P1_NRF52810
// KKM P1 has accelerometer and environment sensor (not implemented)
// We have to initialize I2C to preven KXTJ3 from drawing current
#define HAS_I2C_KXTJ3
// Initialize environment sensor for same reason
#define HAS_LED1_SWITCH
#endif

#ifdef CONFIG_BOARD_KKM_K4P
#define HAS_I2C_LIS2DW12
#define USE_ACCELEROMETER
#define USE_LIS2DW12
#define USE_BUTTON
#endif

#ifdef CONFIG_BOARD_KKM_C2_NRF82805
#define USE_BUTTON
#endif

#if defined(CONFIG_BOARD_NRF52DK_NRF52832)
#define USE_BUTTON
#endif

#ifdef CONFIG_BOARD_WB_20241125
// The board has BQ2512A as switching regulator and requires shutdown via shipping mode
#define HAS_I2C_BQ25121A
#define USE_BQ25121A
#define BATTERY_UVLO_SHUTDOWN
#define BATTERY_LIION
// The beacon will issue shipping mode shutdown when no keys loaded after 5 minutes
// Note: It will require BQ25121A's reset via charging to start working again
#define SHUTDOWN_NOKEYS 300

// Program BQ25121A to 2.5V output, 10mA charge current, 5mA precharge 
#define SYS_VOLTAGE 2500
#define CHARGE_CURRENT 10
#define PRECHARGE_CURRENT 5
#endif

// TX power settings (in dBm)
// Maximum power broadcast
#if defined(CONFIG_SOC_NRF52833) || defined(CONFIG_SOC_NRF54L15) || defined(CONFIG_SOC_NRF52840)
#define TX_POWER_HIGH 8
#else
#define TX_POWER_HIGH 4
#endif
// Normal power output
#define TX_POWER_NORMAL 0
// Low power output
#define TX_POWER_LOW -8

#ifdef BATTERY_LIION
// Li-Ion battery cutoff voltage (will switch to power save mode when it is reached)
// Ignored if BATTERY_UVLO_SHUTDOWN is not defined
#define BATTERY_LOW_VOLTAGE 2800

// Battery levels for Li-Ion batteries (in mV)
#define BATTERY_LEVEL_FULL 4000
#define BATTERY_LEVEL_NORMAL 3700
#define BATTERY_LEVEL_LOW 3300

#else

#define BATTERY_LOW_VOLTAGE 2400

// Battery levels for Lithium non-rechargeable cells (in mV)
#define BATTERY_LEVEL_FULL 3900
#define BATTERY_LEVEL_NORMAL 3700
#define BATTERY_LEVEL_LOW 3400
#endif

#endif

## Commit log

2025-04-25 Added support for LIS2DW12 accelerometer (KKM K4P beacon), various bugfixes
    [lis2dw12.c]
2025-09-30 Added broadcasting accelerometer data as airtag status byte (see update_status_byte() function), automatic shutdown via ship-mode if no keys programmed on beacons with BQ25121A
2025-10-02 Added config for mcuboot to use RTT console and ignore signature of slot0 image
2025-10-02 Fixed battery voltage levels for reports
    [myboards.h]
2025-11-09 Added hardware design for nRF52833 based beacon with Qi/WPC wireless charging
    [Beacon-WirelessCharge-B_Cu.gbr, Beacon-WirelessCharge-B_Fab.gbr, Beacon-WirelessCharge-B_Mask.gbr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]
2026-01-03 correct verbage
    fairly certain you meant minimize power usage not "maximize"
2026-01-10 Added button support to turn off/on for KKM C2, KKM K4P beacons and nRF52DK board
2026-01-11 Added note about high power consumption after using RTT interface to flash/debug
2026-01-13 Fixed button definition for KKM C2
    [myboards.h]
2026-04-22 Update battery status right away, not waiting key change interval
